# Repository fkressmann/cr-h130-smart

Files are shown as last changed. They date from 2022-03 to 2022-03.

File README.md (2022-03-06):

# Teac CR-H130 controller
Okay so you got a Teac CR-H130. You like the sound, and you don't want to replace it. 
But you want to remote control it with your smart home system. What do you do? 

Yep, you could emulate the IR signals from the remote control - mine was dead, no way to retrieve the codes 
(yes I could have bought a new one - but everyone can 'buy').
So I tried to emulate the buttons with an ESP8266. 
As I only use the AUX input, I just need on/off and volume up and down.

## Digging into CR-H130
The volume knob is a normal rotary encoder, the power button is just a button.
All buttons are pulled up to a certain voltage (forgot which). A button press pulls the line to GND.
To emulate button presses, one can use a NPN to programmatically pull the lines to GND.
After hooking everything up fo test, it looked like that:
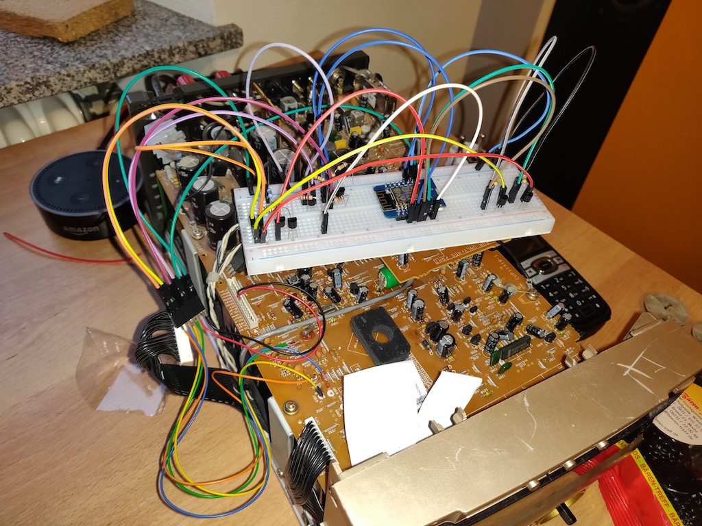
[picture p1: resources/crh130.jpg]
testing on breadboard

As the CD changer in my CR-H130 is dead, too, I previously unplugged it (the black connector on the left) 
to stop the machine from trying to initialize the changer (which resulted in strange noise).
This way I can use the power supply for the changer to power the ESP.

As the breadboard is not really pretty, I soldered everything to a piece of perfboard and used some pin headers to make the ESP pluggable.
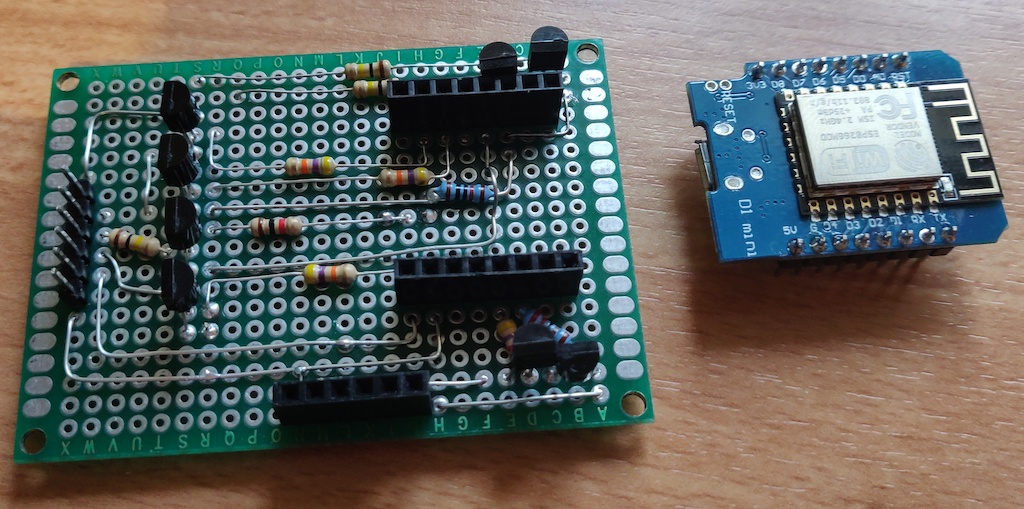
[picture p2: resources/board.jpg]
soldered board

(The pin header on the bottom was for powering some unrelated stuff... just ignore it)

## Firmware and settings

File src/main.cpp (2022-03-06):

#include <ArduinoOTA.h>
#include <ESP8266WiFi.h>
#include <ESP8266mDNS.h>
#include <PubSubClient.h>
#include <WiFiUdp.h>
#include <credentials.h>

const String commandPrefix = MQTT_PREFIX + String("cmnd/");
const char *deviceName = DEVICE_NAME;

WiFiClient espClient;
PubSubClient client(espClient);

int ampVol = 0;
int ampVolDelay = 15;
boolean ampPower = false;
boolean volRead = false;
String tele = "tele";
#define VU D7
#define VD D8
#define VR D0
#define PR D5
#define PW D2
#define LED D4
#define OC1 D1
#define OC2 D6

void sendData(String subtopic, String data, bool retained) {
  Serial.println("SENDING: " + subtopic + ":" + data);
  subtopic = MQTT_PREFIX + subtopic;
  client.publish(subtopic.c_str(), data.c_str(), retained);
}

void sendData(String subtopic, String data) {
  sendData(subtopic, data, false);
}

void log(String line) {
  sendData("log", line, true);
}

void checkEncoderAngle() {
  if (digitalRead(VR) != volRead) {
    volRead = digitalRead(VR);
    if (volRead) {
      sendData("volume/angle", "BAD");
      digitalWrite(LED, HIGH);
    } else {
      sendData("volume/angle", "OK");
      digitalWrite(LED, LOW);
    }
  }
}

void checkAmpPower() {
  if (digitalRead(PR) == ampPower) {
    ampPower = !digitalRead(PR);
    if (ampPower) {
      sendData("power/state", "ON");
    } else {
      sendData("power/state", "OFF");
    }
  }
}

void ampVolUp(int steps) {
  for (int i = 0; i < steps; i++) {
    digitalWrite(VU, HIGH);
    digitalWrite(LED, LOW);
    delay(ampVolDelay);
    digitalWrite(VD, HIGH);
    delay(ampVolDelay);
    digitalWrite(VU, LOW);
    delay(ampVolDelay);
    digitalWrite(VD, LOW);
    digitalWrite(LED, HIGH);
    delay(ampVolDelay);
  }
}

void ampVolDown(int steps) {
  for (int i = 0; i < steps; i++) {
    digitalWrite(VD, HIGH);
    digitalWrite(LED, LOW);
    delay(ampVolDelay);
    digitalWrite(VU, HIGH);
    delay(ampVolDelay);
    digitalWrite(VD, LOW);
    delay(ampVolDelay);
    digitalWrite(VU, LOW);
    digitalWrite(LED, HIGH);
    delay(ampVolDelay);
  }
}

void ampVolSync() {
  log("Syncing Volume to 42");
  // Go down more steps than supported by amp, so we get to 0 volume
  ampVolDown(65);
  delay(ampVolDelay);
  ampVolUp(42);
  ampVol = 42;
  sendData("volume/state", String(42));
}

void ampPowerToggle() {
  digitalWrite(PW, HIGH);
  delay(50);
  digitalWrite(PW, LOW);
}

void reconnect() {
  // Loop until we're reconnected
  while (!client.connected()) {
    Serial.print("Attempting MQTT connection...");
    // Attempt to connect
    // if you MQTT broker has clientID,username and password
    // please change following line to    if (client.connect(clientId,userName,passWord))
    if (client.connect(deviceName)) {
      Serial.println("connected");
      // once connected to MQTT broker, subscribe command if any
      client.subscribe((commandPrefix + '#').c_str());
      sendData("ip", WiFi.localIP().toString(), true);
      sendData("rssi", String(WiFi.RSSI()), true);
    } else {
      Serial.print("failed, rc=");
      Serial.print(client.state());
      Serial.println(" try again in 5 seconds");
      // Wait 6 seconds before retrying
      delay(6000);
    }
  }
} // end reconnect()

void callback(char *topic, byte *payload, unsigned int length) {
  String plString = String((char *)payload);
  String tpString = String(topic);

  // Amp Power
  if (tpString.equals(commandPrefix + "power")) {
    if (plString.equals("ON")) {
      if (!ampPower) {
        ampPowerToggle();
      }
    } else {
      if (ampPower) {
        ampPowerToggle();
      }
    }
  }

  // Amp Volume
  if (tpString.equals(commandPrefix + "volume")) {

    if (plString.equals("SYNC")) {
      if (volRead) {
        ampVolSync();
      } else {
        log("Can't sync, Vol Read not 1-1");
      }
    } else {
      int vol = plString.toInt();

      log("Setting Volume to: " + String(vol));
      if (vol >= 0 && vol <= 63 && ampPower) {
        if (vol < ampVol) {
          ampVolDown(ampVol - vol);
        } else {
          ampVolUp(vol - ampVol);
        }
        ampVol = vol;
      }
      sendData("volume/state", String(ampVol));
    }
  }

  // open collector output 1, supports PWM
  if (tpString.equals(commandPrefix + "oc1")) {
    if (plString.equals("ON")) {
      digitalWrite(OC1, HIGH);
    } else if (plString.equals("OFF")) {
      digitalWrite(OC1, LOW);
    } else {
      int duty = plString.toInt();
      analogWrite(OC1, duty * 10.23);
    }
  }

  // open collector output 1, supports PWM
  if (tpString.equals(commandPrefix + "oc2")) {
    if (plString.equals("ON")) {
      digitalWrite(OC2, HIGH);
    } else if (plString.equals("OFF")) {
      digitalWrite(OC2, LOW);
    } else {
      int duty = plString.toInt();
      analogWrite(OC2, duty * 10.23);
    }
  }
}

void setup() {
  Serial.begin(115200);
  pinMode(VU, OUTPUT);
  pinMode(VD, OUTPUT);
  pinMode(VR, INPUT);
  pinMode(PR, INPUT);
  pinMode(PW, OUTPUT);
  pinMode(LED, OUTPUT);
  pinMode(OC1, OUTPUT);
  pinMode(OC2, OUTPUT);
  WiFi.mode(WIFI_STA);
  WiFi.hostname(deviceName);
  WiFi.begin(WIFI_SSID, WIFI_PSK);
  while (WiFi.waitForConnectResult() != WL_CONNECTED) {
    Serial.println("Connection Failed! Rebooting...");
    delay(5000);
    ESP.restart();
  }

  client.setServer(MQTT_SERVER, 1883);
  client.setCallback(callback);
  reconnect();

  ArduinoOTA.setHostname(deviceName);

  ArduinoOTA.onStart([]() {
    String type;
    if (ArduinoOTA.getCommand() == U_FLASH) {
      type = "sketch";
    } else { // U_FS
      type = "filesystem";
    }

    // NOTE: if updating FS this would be the place to unmount FS using FS.end()
    Serial.println("Start updating " + type);
  });
  ArduinoOTA.onEnd([]() {
    Serial.println("\nEnd");
  });
  ArduinoOTA.onProgress([](unsigned int progress, unsigned int total) {
    Serial.printf("Progress: %u%%\r", (progress / (total / 100)));
  });
  ArduinoOTA.onError([](ota_error_t error) {
    Serial.printf("Error[%u]: ", error);
    if (error == OTA_AUTH_ERROR) {
      Serial.println("Auth Failed");
    } else if (error == OTA_BEGIN_ERROR) {
      Serial.println("Begin Failed");
    } else if (error == OTA_CONNECT_ERROR) {
      Serial.println("Connect Failed");
    } else if (error == OTA_RECEIVE_ERROR) {
      Serial.println("Receive Failed");
    } else if (error == OTA_END_ERROR) {
      Serial.println("End Failed");
    }
  });
  ArduinoOTA.begin();
  Serial.println("Ready");
  Serial.print("IP address: ");
  Serial.println(WiFi.localIP());
  sendData(tele, "UP", true);

  checkAmpPower();
  if (ampPower) {
    delay(1000);
    ampVolSync();
  }
}

void loop() {
  ArduinoOTA.handle();
  if (!client.connected()) {
    reconnect();
  }
  client.loop();
  checkEncoderAngle();
  checkAmpPower();
}
